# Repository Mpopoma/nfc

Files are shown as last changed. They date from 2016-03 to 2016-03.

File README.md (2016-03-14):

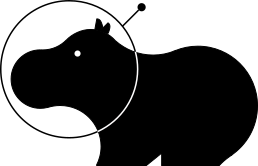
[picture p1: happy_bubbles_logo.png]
Happy Bubbles Logo


# Happy Bubbles - Wifi NFC Device

This device is in the "Happy Bubbles" series of open hardware and open source IoT and home-automation devices. The Wifi NFC device is easy to use, easy to make yourself, and cheap. 

Its purpose is to send NFC/RFID tags that you touch to it to an HTTP URL on whatever server you'd like.

What you need to build it:
 * a NodeMCU ESP8266 development kit - [buy one here](http://amzn.to/1S03qNE)
 * an RC522 RFID module - [buy one here](http://amzn.to/1U1rVxE)
 * (optional) a WS2812B RGB LED

## How to set it up

#### 0. Initial flashing

Easiest is to download the  release and use your favorite ESP8266 flashing tool to flash the bootloader, the firmware, and blank settings. Detailed instructions are provided in the release notes, thanks tve!

#### 1. Wire it up 
| RC522 NFC pin | NodeMCU pin |  ESP8266 GPIO |
|---|:---:|---:|
| SDA | D8 | GPIO 15 |
| SCK | D5 | GPIO 14 |
| MOSI | D7 | GPIO 13 |
| MISO | D6 | GPIO 12 |
| IRQ | Not connected| Not connected |
| GND | Ground / GND | Ground |
| RST | D4 | GPIO 2 |
| 3.3V | 3.3V / VCC | VCC |

If there is interest, I can create a PCB for you guys to make this easier. Let me know if anyone would like these and I could put them up for sale.

#### 2. Optional WS2812B LED

An RGB LED is useful as a status indicator to tell you when you're in config-mode, when a tag is hit, and the server response can even change its colour!

| WS2812 pin | NodeMCU pin |  ESP8266 GPIO |
|---|:---:|---:|
| GND | GND | GND |
| Data-In | D1 | GPIO 5 |
| 5V Power | VIN | not applicable |

#### 3. Powering it up
Just insert a microUSB cable in the NodeMCU! When it boots up, its red LED should be lit. If you have a WS2812b hooked up, it will glow orange.

If it doesn't, try holding the "FLASH: button on the nodeMCU board held down for about 10 seconds. Holding the button down lets to change between config mode and RFID-scanning mode. I left these two seperate for security, so that while your device is acting as an RFID scanner, someone can't just connect to its hostname and start messing with your settings.

#### 4. Connect it to your wifi network
1. With the board powered up, the Happy Bubbles NFC device will automatically start an access point you can connect to called "happy-bubbles-nfc". 
2. Connect to this access point with your computer
3. Open a browser and visit http://192.168.4.1/
4. You'll now be at the Happy Bubbles config screen! You can change the hostname of the device here.
5. On the left side with the navigation bar, go to "WiFi Setup". It will populate a bunch of wifi access points it can see. Find yours and type in the password. You should see it get an IP address from it, and now you're connected!

#### 5. Make it hit your server
1. From the same  config mode, go to "NFC Setup". In there, you can set some parameters for how the JSON request from the Happy Bubbles device will go to your server.
2. The most important one here is the HTTP URL, this URL will receive a POST request from the device when a tag is scanned.
3. The 'Device ID' is a name you can give this device that will also be included in the JSON. This is useful if you have more than one Happy Bubbles NFC device around and you want to know which one the request is coming from.
4. The 'Device Secret' and 'Device counter' are optional but useful if you want to authenticate the requests to make sure someone isn't spoofing a tag. 

#### 5. Make it run!

Hold down the "FLASH" button on the NodeMCU board for about 10 seconds. The red LED on the NodeMCU should turn on, and if you have an RGB LED hooked up, it will blink purple a few times, fast. It's now reading tags! Every time you touch a tag, the RGB LED will light pink quickly.

## Communication

#### HTTP Request
Every time you touch a tag to the device, it will send an HTTP POST request to the URL you specified in the config. The REQUEST payload will be JSON that looks like this:
```
{
  "device_id": "CONFIG-DEVICE-ID", 
  "tag_uid": "THE-TAGS-UUID", 
  "counter": 3, 
  "hash": "7cac4442e6caf834ce20a359ff7ee9ff34525691"
}
```

The "device_id" is the "Device ID" you specified in the config. The "tag_uuid" is the unique ID of the tag that was detected by the reader. The "counter" and "hash" are optional security authentication parameters described below in the "Optional Authentication" section.

#### HTTP Response
After you touch the tag, the device expects a 200 OK response with a JSON payload. Don't worry about having to send one, it's optional:
```
{
  "r":5,
  "g":250,
  "b":2,
  "delay":2000
}
```

The "r", "g", and "b" are RGB colour values for the optional WS2812B LED. The server could tell the LED to light up a certain way after the request. This way you could give the user some kind of indication of what happened. 

The "delay" is the number of milliseconds to keep the color after a request. If you make it 0, the LED will stay lit that way forever, or until the next reqest...or until you remove power!

## Optional Authentication
The way this authentication works is that the Happy Bubbles NFC device will send a "hash" string in its JSON response. This "hash" is an SHA1-based HMAC, its input is the device-id, the NFC tag-ID, and the counter all concatenated together with no spaces. The 'counter' increments every time your server sends back a 200 OK response. It is used as a 'nonce' to prevent replay attacks on this authentication mechanism.
This string is then SHA1-HMAC'd hashed against the "device secret" from the config menu. You can use this on the backend to ensure no one is spoofing tag-hits, it's optional.

### Credits

This project wouldn't have been possible without my standing on the shoulders of giants such as:
 * [NodeMCU](https://github.com/nodemcu/nodemcu-devkit-v1.0) - The ESP8266-based hardware that this project uses.
 * [esp-link](https://github.com/jeelabs/esp-link) - The firmware for this project is a modified subset of the what JeeLabs' "esp-link" project has built and made this whole thing really nice and easy to work with. 
 * [Espressif](http://espressif.com) - for making the amazing ESP8266 project that enables things like this to even be possible. A wonderful product from a wonderful company.
 * [esphttpd](http://www.esp8266.com/wiki/doku.php?id=esp-httpd) - SpriteTM made an awesome little HTTP webserver for the ESP8266 that powers the config menu of the esp-link and the Happy Bubbles NFC device
 * everyone in the ESP8266 community who shares their code and advice.

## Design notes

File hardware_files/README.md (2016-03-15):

Happy Bubbles Logo

# Happy Bubbles - Wifi NFC Device

These are the hardware files, in Eagle format, for the Happy Bubbles NFC device.

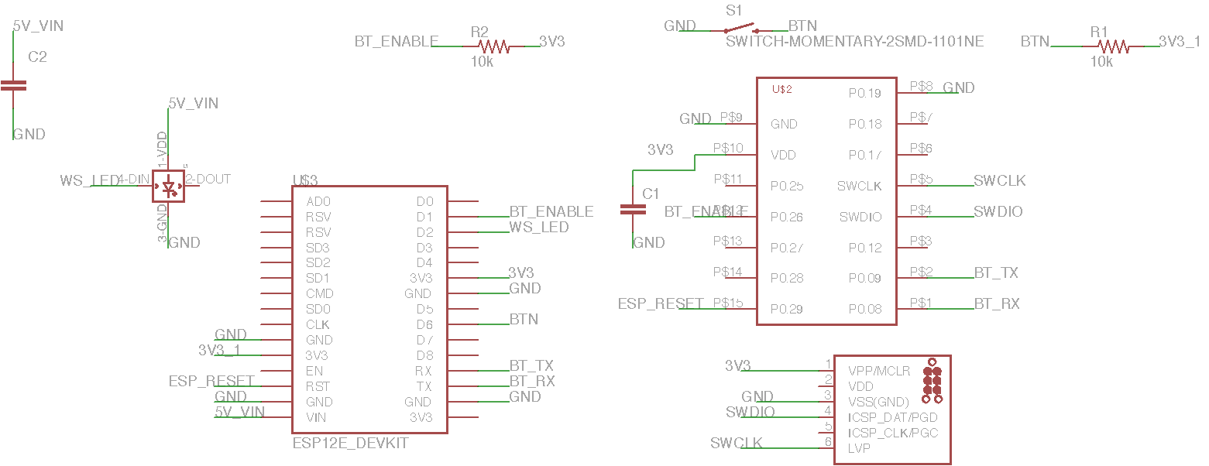
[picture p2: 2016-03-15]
hardware_files/schematic.png

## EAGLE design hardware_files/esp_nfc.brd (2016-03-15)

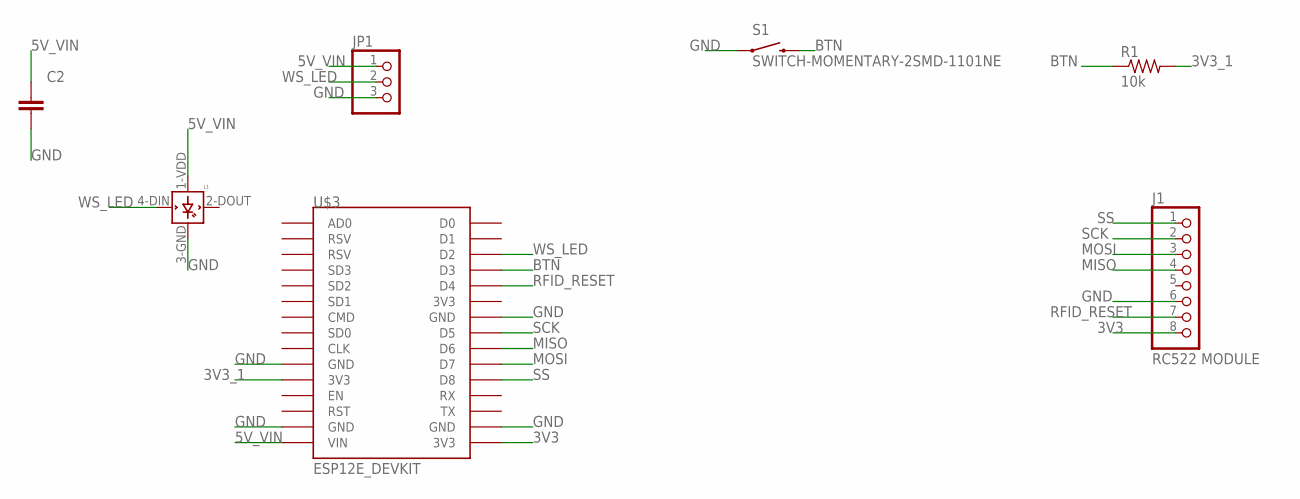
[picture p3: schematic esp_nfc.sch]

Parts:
C2: CAPACITOR_NPOL-0603; C603
J1: RC522 MODULE; 1X08-LOCK
JP1: PINHD-1X3; 1X03
L1: WS2812B
R1: 10k; R0603
S1: SWITCH-MOMENTARY-2SMD-1101NE; TACTILE-SWITCH-1101NE
U$3: ESP12E_DEVKIT

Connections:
3V3: J1.8, U$3.3V3@2 (3V3)
3V3_1: R1.2, U$3.3V3@0 (3V3)
5V_VIN: C2.1, JP1.1, L1.1-VDD (VDD), U$3.VIN
BTN: R1.1, S1.2, U$3.D3
GND: C2.2, J1.6, JP1.3, L1.3-GND (GND), S1.1, U$3.GND@0 (GND), U$3.GND@1 (GND), U$3.GND@2 (GND), U$3.GND@3 (GND)
MISO: J1.4, U$3.D6
MOSI: J1.3, U$3.D7
RFID_RESET: J1.7, U$3.D4
SCK: J1.2, U$3.D5
SS: J1.1, U$3.D8
WS_LED: JP1.2, L1.4-DIN (DIN), U$3.D2

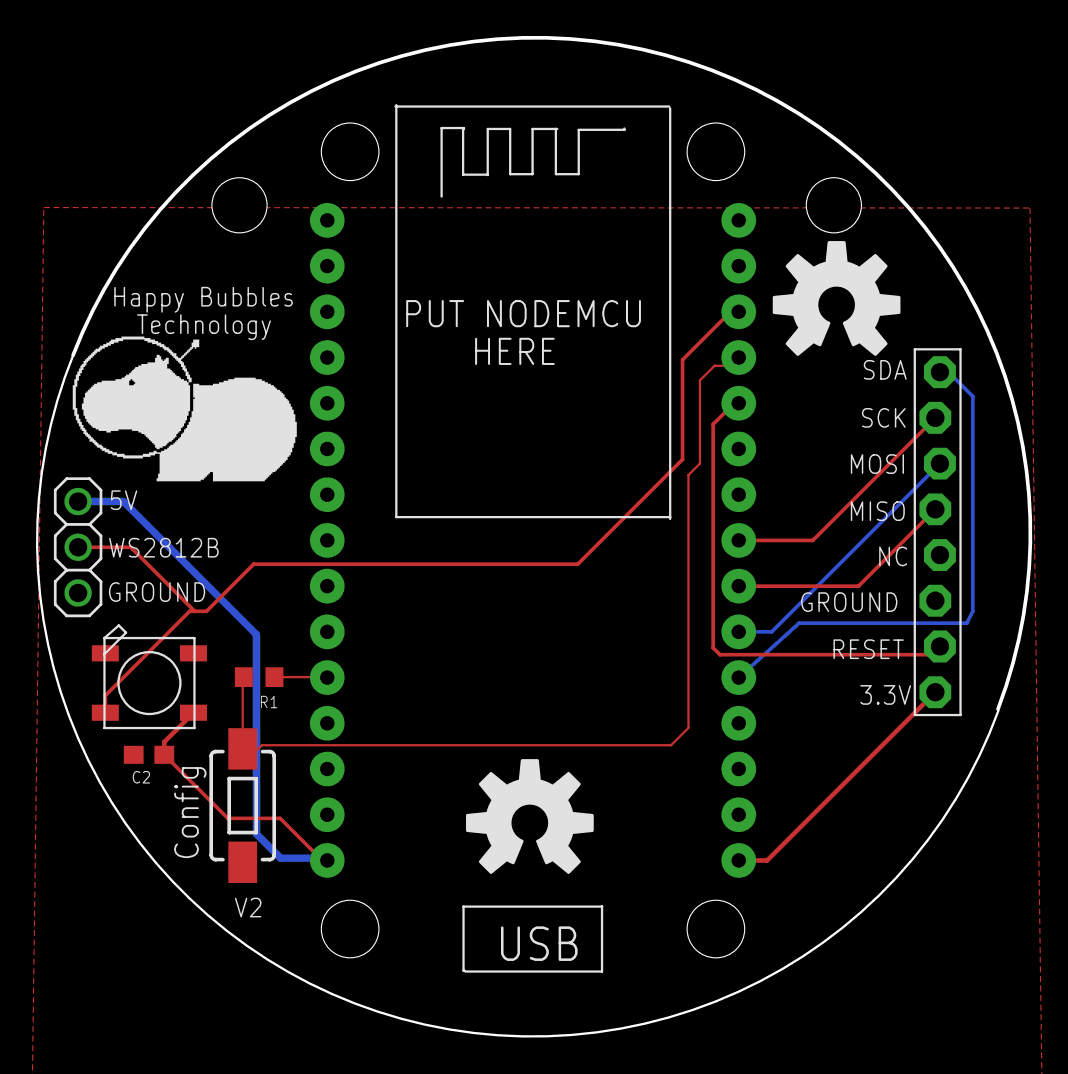
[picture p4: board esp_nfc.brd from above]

Board: 2 copper layers, 55.2 x 55.5 mm, 11 parts (1 on the bottom side), 11 nets.

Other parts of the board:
U$1: HAPPY_HIPPO_500MIL
U$4, U$6: OSHW-LOGO-L
U$5: HAPPY_HIPPO

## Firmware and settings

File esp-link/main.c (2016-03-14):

/*
* ----------------------------------------------------------------------------
* "THE BEER-WARE LICENSE" (Revision 42):
* Jeroen Domburg <jeroen@spritesmods.com> wrote this file. As long as you retain
* this notice you can do whatever you want with this stuff. If we meet some day,
* and you think this stuff is worth it, you can buy me a beer in return.
* ----------------------------------------------------------------------------
* Heavily modified and enhanced by Thorsten von Eicken in 2015
* ----------------------------------------------------------------------------
*/

#include <esp8266.h>
#include "httpd.h"
#include "httpdespfs.h"
#include "cgi.h"
#include "cgiwifi.h"
#include "cgitcp.h"
#include "cginfc.h"
#include "cgiflash.h"
#include "auth.h"
#include "espfs.h"
#include "uart.h"
#include "config.h"
#include "log.h"
#include "gpio.h"
#include "cgiservices.h"

#include "gpio16.h"

#define PERIPHS_IO_MUX_PULLDWN          BIT6
#define PIN_PULLDWN_DIS(PIN_NAME)             CLEAR_PERI_REG_MASK(PIN_NAME, PERIPHS_IO_MUX_PULLDWN)

/*
#define NOTICE(format, ...) do {	                                          \
	LOG_NOTICE(format, ## __VA_ARGS__ );                                      \
	os_printf(format "\n", ## __VA_ARGS__);                                   \
} while ( 0 )
*/
#define NOTICE(format, ...) do {	                                          \
	os_printf(format "\n", ## __VA_ARGS__);                                   \
} while ( 0 )

/*
This is the main url->function dispatching data struct.
In short, it's a struct with various URLs plus their handlers. The handlers can
be 'standard' CGI functions you wrote, or 'special' CGIs requiring an argument.
They can also be auth-functions. An asterisk will match any url starting with
everything before the asterisks; "*" matches everything. The list will be
handled top-down, so make sure to put more specific rules above the more
general ones. Authorization things (like authBasic) act as a 'barrier' and
should be placed above the URLs they protect.
*/
HttpdBuiltInUrl builtInUrls[] = {
  { "/", cgiRedirect, "/home.html" },
  { "/menu", cgiMenu, NULL },
  { "/flash/next", cgiGetFirmwareNext, NULL },
  { "/flash/upload", cgiUploadFirmware, NULL },
  { "/flash/reboot", cgiRebootFirmware, NULL },
//  { "/pgm/sync", cgiOptibootSync, NULL },
//  { "/pgm/upload", cgiOptibootData, NULL },
//  { "/log/text", ajaxLog, NULL },
//  { "/log/dbg", ajaxLogDbg, NULL },
//  { "/log/reset", cgiReset, NULL },
//  { "/console/reset", ajaxConsoleReset, NULL },
//  { "/console/baud", ajaxConsoleBaud, NULL },
//  { "/console/text", ajaxConsole, NULL },
//  { "/console/send", ajaxConsoleSend, NULL },
  //Enable the line below to protect the WiFi configuration with an username/password combo.
  //    {"/wifi/*", authBasic, myPassFn},
  { "/wifi", cgiRedirect, "/wifi/wifi.html" },
  { "/wifi/", cgiRedirect, "/wifi/wifi.html" },
  { "/wifi/info", cgiWifiInfo, NULL },
  { "/wifi/scan", cgiWiFiScan, NULL },
  { "/wifi/connect", cgiWiFiConnect, NULL },
  { "/wifi/connstatus", cgiWiFiConnStatus, NULL },
  { "/wifi/setmode", cgiWiFiSetMode, NULL },
  { "/wifi/special", cgiWiFiSpecial, NULL },
  { "/wifi/apinfo", cgiApSettingsInfo, NULL },
  { "/wifi/apchange", cgiApSettingsChange, NULL },  
  { "/system/info", cgiSystemInfo, NULL },
  { "/system/update", cgiSystemSet, NULL },
  { "/services/info", cgiServicesInfo, NULL },
  { "/services/update", cgiServicesSet, NULL },

  { "/nfc", cgiNFC, NULL },

  { "*", cgiEspFsHook, NULL }, //Catch-all cgi function for the filesystem

  { NULL, NULL, NULL }
};

static ETSTimer configModeTimer;

#ifdef SHOW_HEAP_USE
static ETSTimer prHeapTimer;
static void ICACHE_FLASH_ATTR prHeapTimerCb(void *arg) {
  os_printf("Heap: %ld\n", (unsigned long)system_get_free_heap_size());
}
#endif

# define VERS_STR_STR(V) #V
# define VERS_STR(V) VERS_STR_STR(V)
char* esp_link_version = VERS_STR(VERSION);

// address of espfs binary blob
extern uint32_t _binary_espfs_img_start;

extern void app_init(void);

void user_rf_pre_init(void) {
  //default is enabled
  system_set_os_print(DEBUG_SDK);
}

#define BUTTON_GPIO 0 

bool is_config_button_pressed(void) 
{
	if(!GPIO_INPUT_GET(BUTTON_GPIO))
	{
		return true;
	}
	return false;
}

void stupid_restart(void) 
{
	//force watchdog reset
	while(1){};
}

static int config_button_count = 0;
bool should_config(void) 
{
	if(is_config_button_pressed())
	{
		NOTICE("config button was pressed");
		if(config_button_count > 2)
		{
			//toggle config mode, on next restart
			flashConfig.configMode = !flashConfig.configMode;
			configSave();
			NOTICE("config button was pressed > 3, doing RESTART!");
			stupid_restart();
		}
		config_button_count++;
	}
	else
	{
		//restart counter if not pressed
		config_button_count = 0;
	}
}

// Main routine to initialize esp-link.
void user_init(void) {
  // get the flash config so we know how to init things
  //configWipe(); // uncomment to reset the config for testing purposes
  bool restoreOk = configRestore();
  // Init gpio pin registers
  gpio_init();
  gpio_output_set(0, 0, 0, (1<<15)); // some people tie it to GND, gotta ensure it's disabled
  // init UART
  //uart_init(flashConfig.baud_rate, 115200);
  uart_init(115200, 115200);
  logInit(); // must come after init of uart
  // Say hello (leave some time to cause break in TX after boot loader's msg
  os_delay_us(10000L);
  os_printf("\n\n** %s\n", esp_link_version);
  os_printf("Flash config restore %s\n", restoreOk ? "ok" : "*FAILED*");

	// //turn off the red LED on the boards
	gpio16_output_conf();
	gpio16_output_set(1);

	PIN_FUNC_SELECT(PERIPHS_IO_MUX_GPIO0_U, FUNC_GPIO0);
	PIN_PULLUP_DIS(PERIPHS_IO_MUX_GPIO0_U);
	PIN_PULLDWN_DIS(PERIPHS_IO_MUX_GPIO0_U);
	
  // Wifi
  wifiInit();

  os_timer_disarm(&configModeTimer);
	os_timer_setfn(&configModeTimer, should_config, NULL);
  os_timer_arm(&configModeTimer, 1000, 1);

	// init the flash filesystem with the html stuff
  espFsInit(&_binary_espfs_img_start);
	
	if(flashConfig.configMode)
	{
  	EspFsInitResult res = espFsInit(&_binary_espfs_img_start);
  	os_printf("espFsInit %s\n", res?"ERR":"ok");
  	// mount the http handlers
	  httpdInit(builtInUrls, 80);
#ifdef SHOW_HEAP_USE
  	os_timer_disarm(&prHeapTimer);
	  os_timer_setfn(&prHeapTimer, prHeapTimerCb, NULL);
  	os_timer_arm(&prHeapTimer, 10000, 1);
#endif
	}

  struct rst_info *rst_info = system_get_rst_info();
  NOTICE("Reset cause: %d=%s", rst_info->reason, rst_codes[rst_info->reason]);
  NOTICE("exccause=%d epc1=0x%x epc2=0x%x epc3=0x%x excvaddr=0x%x depc=0x%x",
    rst_info->exccause, rst_info->epc1, rst_info->epc2, rst_info->epc3,
    rst_info->excvaddr, rst_info->depc);
  uint32_t fid = spi_flash_get_id();
  NOTICE("Flash map %s, manuf 0x%02lX chip 0x%04lX", flash_maps[system_get_flash_size_map()],
      fid & 0xff, (fid&0xff00)|((fid>>16)&0xff));
  NOTICE("** esp-link ready");

	float brightness = 0.5;

	set_led(0, 0, 0, 0);
  os_delay_us(10);
	// orange for config
	set_led((int)(255*brightness), (int)(69*brightness), 0, 0);

	if(flashConfig.configMode)
	{
		NOTICE("ENTERING CONFIG MODE");
	  cgiServicesSNTPInit();
	
		// turn on the red LED on the boards
		gpio16_output_conf();
		gpio16_output_set(0);

	}
	else
	{
		NOTICE("INITIALIZING USER APPLICATION");
	  app_init();

	}
}

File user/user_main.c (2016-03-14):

#include <esp8266.h>
#include <config.h>
#include "osapi.h"

#include "espfs.h"

#include "stdout.h"
#include "gpio16.h"

#include "mfrc522.h"
#include "httpclient.h"
#include "jsmn.h"
#include "hmac_sha1.h"

#define PERIPHS_IO_MUX_PULLDWN          BIT6
#define PIN_PULLDWN_DIS(PIN_NAME)             CLEAR_PERI_REG_MASK(PIN_NAME, PERIPHS_IO_MUX_PULLDWN)
#define sleepms(x) os_delay_us(x*1000);

#define RFID_LOOP_DELAY 200 
#define LAST_TAG_TIME_THRESHOLD 5 // 5 seconds

//0 is lowest priority
#define procTaskPrio        0
#define procTaskQueueLen    1

static os_timer_t rfid_timer;
static bool did_sync_once = false;

static uint32_t rtc_delta_secs = 0;
static char last_tag [64];
static uint32_t last_tag_time = 0;

static char secret [50];
static char device_id [30];

static bool led_toggle = false;

uint32_t atoint32(char *instr)
{
  uint32_t retval;
  int i;

  retval = 0;
  for (; *instr; instr++) {
    retval = 10*retval + (*instr - '0');
  }
  return retval;
}

void ICACHE_FLASH_ATTR create_json(char * output, char * dev_id, char * tag_uid, uint32_t counter, char * hash)
{
	os_sprintf(output, "{\"device_id\": \"%s\",\r\n\"tag_uid\": \"%s\",\r\n\"counter\": %ld,\r\n\"hash\": \"%s\"}", dev_id, tag_uid, counter, hash);
}

void strip_newlines(char * inbuff, int len, char * outbuff)
{
	if( inbuff[len-1] == '\n' )
	{
		    inbuff[len-1] = 0;
	}
	strcpy(outbuff, inbuff);
}

bool is_connected()
{
	int x=wifi_station_get_connect_status();
	if (x != STATION_GOT_IP) {
		return false;
	}
	return true;
}

void ICACHE_FLASH_ATTR get_serial_secret()
{
	strcpy(secret, flashConfig.nfc_device_secret);
	strcpy(device_id, flashConfig.nfc_device_id);
}

uint32_t get_time_secs()
{
	uint32_t out = (system_get_time() / 1000000) + rtc_delta_secs;
	return out;
}

os_event_t    procTaskQueue[procTaskQueueLen];

static void ICACHE_FLASH_ATTR
procTask(os_event_t *events)
{
	system_os_post(procTaskPrio, 0, 0 );
	if( events->sig == 0 && events->par == 0 )
	{
		//Idle Event.
	}
}

void ICACHE_FLASH_ATTR hex2str(char *out, unsigned char *s, size_t len)
{
	char tmp_str[3];
	memset(out, 0, 40);
	memset(tmp_str, 0, 3);
	os_sprintf(tmp_str, "%02x", s[0]);
	strcpy(out, tmp_str);
	int ii;
	for(ii=1; ii<len; ii++)
	{
		memset(tmp_str, 0, 3);
		os_sprintf(tmp_str,"%02x", s[ii]);
		strcat(out, tmp_str);
	}
}

void up_count() {
	uint32_t counter = flashConfig.nfc_counter;
	counter++;
	flashConfig.nfc_counter = counter;
	configSave();
}

/*
 * JSON parsing stuff
 */

jsmn_parser parser;
jsmntok_t tokens[30];

char * json_token_tostr(char *js, jsmntok_t *t)
{
	js[t->end] = '\0';
	return js + t->start;
}

void rfid_http_cb(char * response_body, int http_status, char * full_response)
{
	os_printf("got http response status %d \r\nbody: '%s'\r\n", http_status, response_body);
	if(http_status == 200)
	{
		// parse the return body with jsmn
		jsmn_init(&parser);
		int jp = jsmn_parse(&parser, response_body, strlen(response_body), tokens, 30);

		//try to find color r/g/b's
		int r, g, b = 0;
		int delay = 1000; //milliseconds
		for(int i=1; i<30; i++)
		{
			// red
			if(strcmp(json_token_tostr(response_body, &tokens[i]), "r") == 0)
			{
				r = atoi(json_token_tostr(response_body, &tokens[i+1]));
			}

			// green
			if(strcmp(json_token_tostr(response_body, &tokens[i]), "g") == 0)
			{
				g = atoi(json_token_tostr(response_body, &tokens[i+1]));
			}
			
			// blue
			if(strcmp(json_token_tostr(response_body, &tokens[i]), "b") == 0)
			{
				b = atoi(json_token_tostr(response_body, &tokens[i+1]));
			}
			
			// delay
			if(strcmp(json_token_tostr(response_body, &tokens[i]), "delay") == 0)
			{
				delay = atoi(json_token_tostr(response_body, &tokens[i+1]));
			}
		}

		up_count();
  	set_led(r, g, b, delay);
	}
	else 
	{
  	set_led(255, 0, 0, 900);
	}
	gpio16_output_set(1);
}

void ICACHE_FLASH_ATTR send_tag( char* tag_uid )
{
	static unsigned char hash[HMAC_SHA1_DIGEST_LENGTH];
	static char tosign[200];
	static char json_send[500];
	static char hashstr[40];
	HMAC_SHA1_CTX c;

	strcpy(tosign, device_id);
	strcat(tosign, tag_uid);
	uint32_t counter = flashConfig.nfc_counter;
	char countstr[80];
	os_sprintf(countstr, "%ld", counter);
	strcat(tosign, countstr);
	
	//HMAC_SHA1_Init(&c);
	HMAC_SHA1_Init(&c);
	HMAC_SHA1_UpdateKey(&c, secret, 3);
	HMAC_SHA1_UpdateKey(&c, &(secret[3]), strlen(secret) - 3);
	HMAC_SHA1_EndKey(&c);
  HMAC_SHA1_StartMessage(&c);
	HMAC_SHA1_UpdateMessage(&c, tosign, 7);
	HMAC_SHA1_UpdateMessage(&c, &(tosign[7]), strlen(tosign) - 7);
	HMAC_SHA1_EndMessage(&(hash[0]), &c);
	HMAC_SHA1_Done(&c);

	hex2str(hashstr, hash, 20);
  //os_printf("hashstr with secret %s is %s\n\r", secret, hashstr);
	create_json(json_send, device_id, tag_uid, counter, hashstr);
	//http_get("http://wtfismyip.com/text", rfid_http_cb);
	os_printf("SENDING TAG json: %s \n\r", json_send);
	http_post(flashConfig.nfc_url, json_send, rfid_http_cb);
	
	wait_ms(700);
	gpio16_output_set(0);
}

void ICACHE_FLASH_ATTR rfid_loop()
{
	// Look for new cards
	uint8_t status = PICC_IsNewCardPresent();
	os_printf("status %d - %d - %d\r\n",status, system_get_time() / 1000000, get_time_secs());
	if ( ! (status == STATUS_OK || status == STATUS_COLLISION))
	{
		//wait_ms(500);
		//continue;
		return;
	}

	// Select one of the cards
	if ( ! PICC_ReadCardSerial())
	{
		//wait_ms(500);
		//continue;
		return;
	}

	wait_ms(100);
	
	// short little dance when got a tag
  set_led(233, 90, 99, 150);

	// Print Card UID
	os_printf("Card UID: ");
	char tag_uid [64];
	char tag_tmp [4];
	strcpy(tag_uid, "");
	for (uint8_t i = 0; i < uid.size; i++)
	{
		//os_printf("%02X", uid.uidByte[i]);
		os_sprintf(tag_tmp, "%02x", uid.uidByte[i]);
		strcat(tag_uid, tag_tmp);
	}
	os_printf("%s \n\r", tag_uid);
	// Print Card type
	uint8_t piccType = PICC_GetType(uid.sak);
	os_printf("PICC Type: %s \n\r", PICC_GetTypeName(piccType));

	// use the internal clock for this because time is synced on every request
	// the compensation for drift is often enough to throw off this short re-try period and 
	// send the tag up too often
	uint32_t time_tmp = system_get_time() / 1000000;
	if(strcmp(last_tag, tag_uid) != 0 || time_tmp - last_tag_time > LAST_TAG_TIME_THRESHOLD )
	{
		send_tag(tag_uid);
		strcpy(last_tag, tag_uid);
		last_tag_time = system_get_time() / 1000000;
		//wait_ms(500);
	}
}

//Timer event.
static void ICACHE_FLASH_ATTR rfidTimer(void *arg)
{
	//os_printf("doing rfid loop\r\n");
	rfid_loop();
}
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

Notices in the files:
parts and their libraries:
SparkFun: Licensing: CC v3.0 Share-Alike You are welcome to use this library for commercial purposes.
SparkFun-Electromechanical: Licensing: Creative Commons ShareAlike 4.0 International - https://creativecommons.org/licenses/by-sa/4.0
